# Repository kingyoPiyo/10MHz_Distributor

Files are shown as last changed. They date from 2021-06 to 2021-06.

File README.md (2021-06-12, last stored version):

# 10MHz_Distributor
GPSDOなどの10MHz基準信号の分配基板です。  
出力部に5段のBPFを搭載しており、入力信号をバッファリング＆正弦波へ波形整形してから出力します。 
 
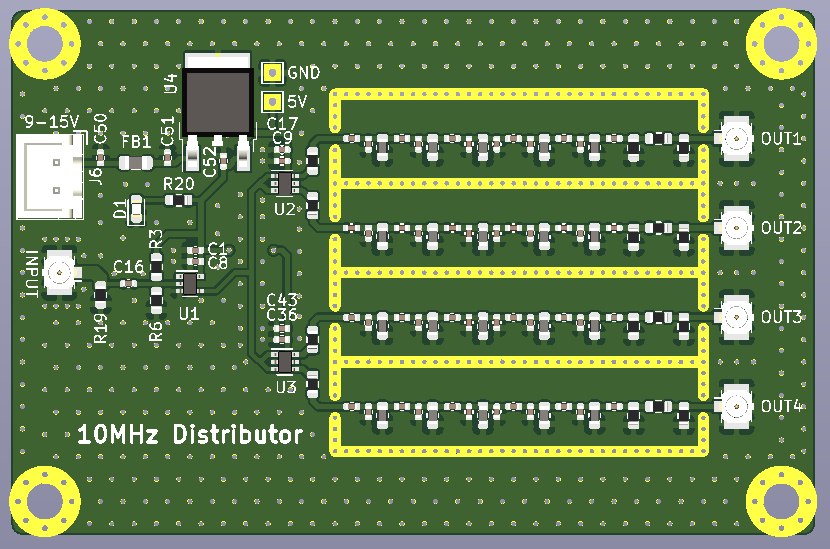
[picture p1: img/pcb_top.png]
  
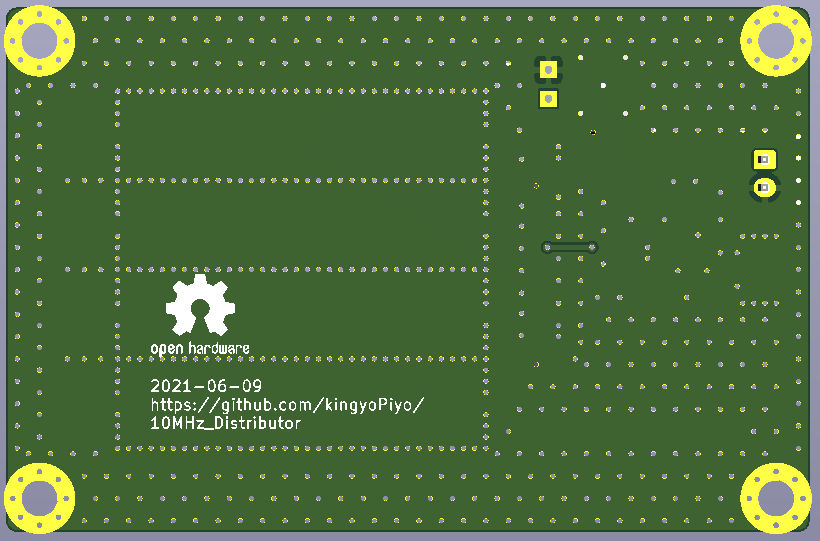
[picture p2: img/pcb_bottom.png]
  

# 諸特性
・・・部品到着、組み立て後に詳細測定予定・・・  

|  項目  |  仕様 |  備考  |
| --- | --- | --- |
|  電源電圧  |  9 ～ 15 V  | NJM7805耐圧は35V |
|  消費電流  |  約 xx mA  | 電源電圧12V, 4出力50Ω終端時 |
|  入力インピーダンス  |  約 xxx Ω  | R19にて50Ω終端可 |
|  入力信号レベル  |  xx ～ xx Vp-p  |  |
|  出力インピーダンス  |  50 Ω  |  |
|  出力信号レベル  |  xx ～ xx dBm  | 50Ω終端時 |
|  スプリアスレベル  |  < -xx dBm (2nd)<br>< -xx dBm (3rd)<br>< -xx dBm (4th)  | 50Ω終端時 |
|  SSB位相雑音  |  -xx dBc/Hz 10kHz offset<br>-xx dBc/Hz 30kHz offset<br>-xx dBc/Hz 100kHz offset  | 50Ω終端時<br>入力信号はxxx |

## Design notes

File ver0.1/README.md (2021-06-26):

# 10MHz_Distributor(ver 0.1)
GPSDOなどの10MHz基準信号の分配基板です。  
出力部に5段のBPFを搭載しており、入力信号をバッファリング＆正弦波へ波形整形してから出力します。 
 
  
  

# 諸特性
インダクタのQ値が考慮できておらず、通過帯域での減衰量が非常に大きくなりました。  
インダクタを変更して再設計します。（続く・・・）  
* インダクタ：LQW18ANR47J00  
* Q値：5.5@10MHz  
* DCR：5.3Ω@10MHz  

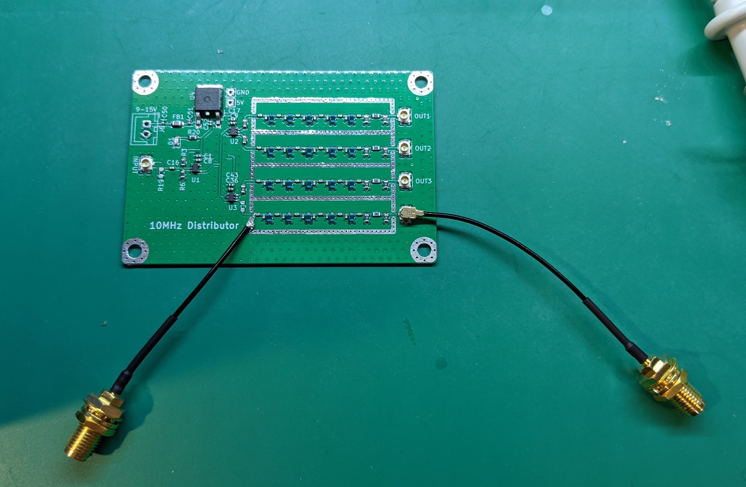
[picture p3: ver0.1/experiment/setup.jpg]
  
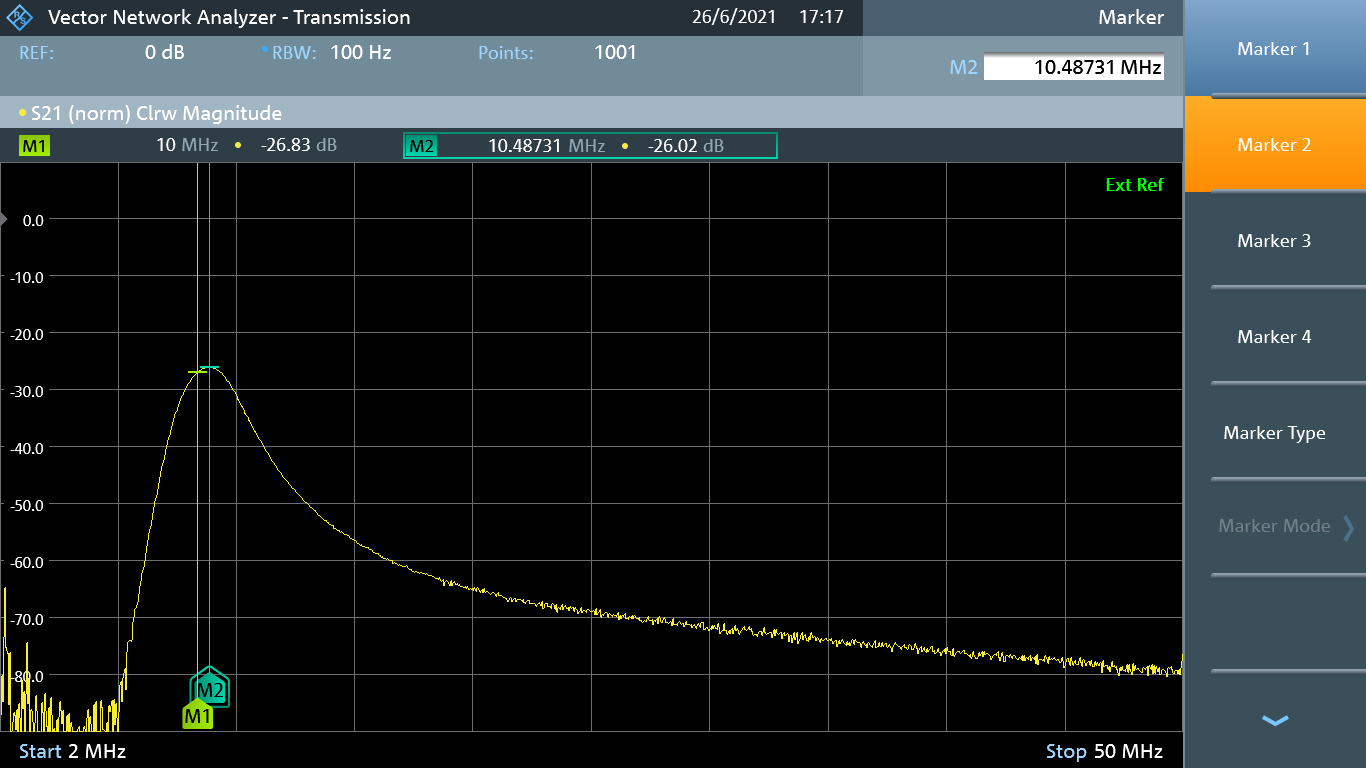
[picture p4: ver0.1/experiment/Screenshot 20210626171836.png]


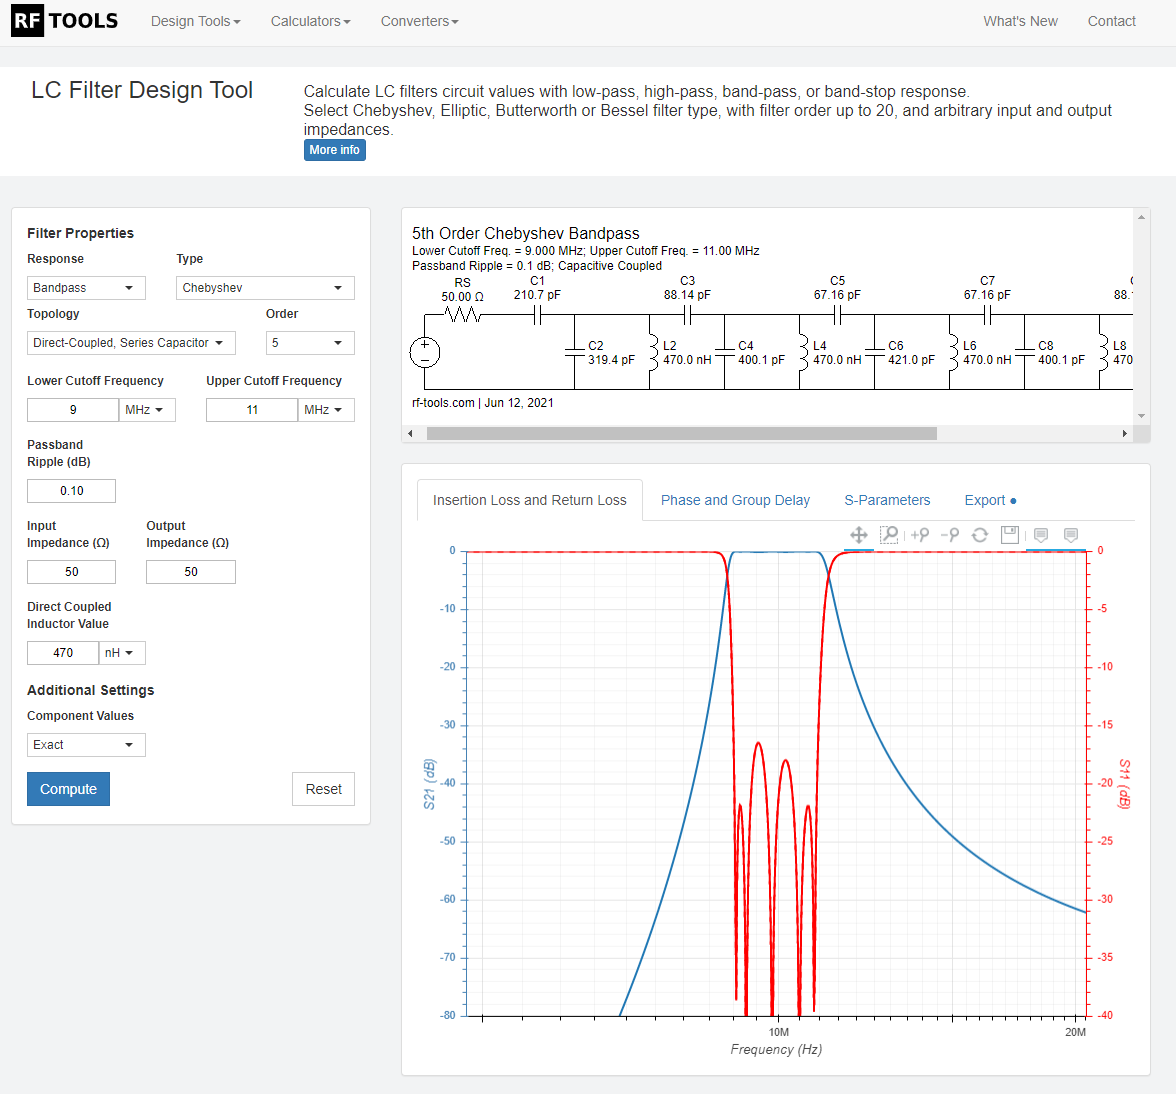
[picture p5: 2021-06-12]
ver0.1/LTspice/LCFilterDesignTool_cap.png

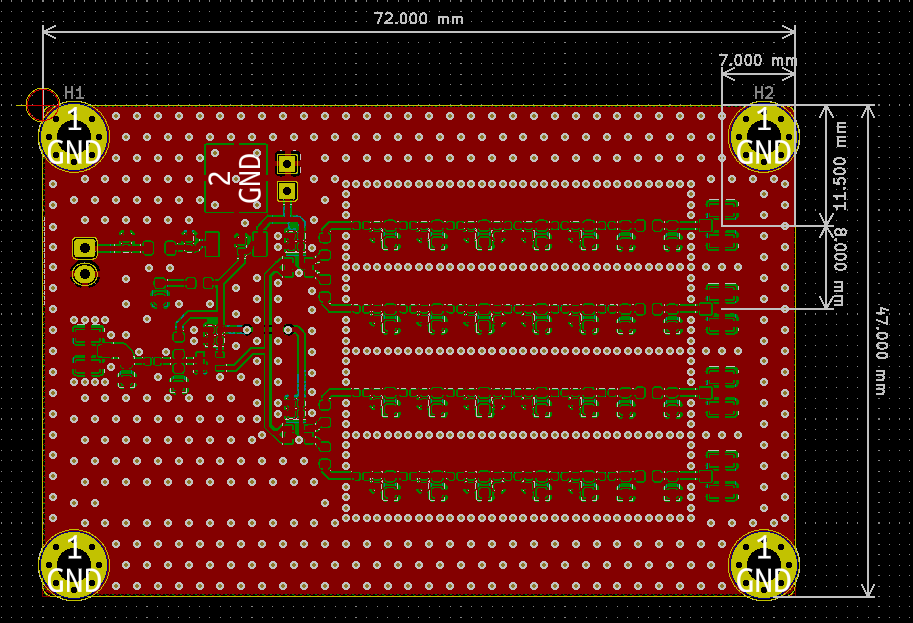
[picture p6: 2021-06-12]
ver0.1/img/pcb_size.png

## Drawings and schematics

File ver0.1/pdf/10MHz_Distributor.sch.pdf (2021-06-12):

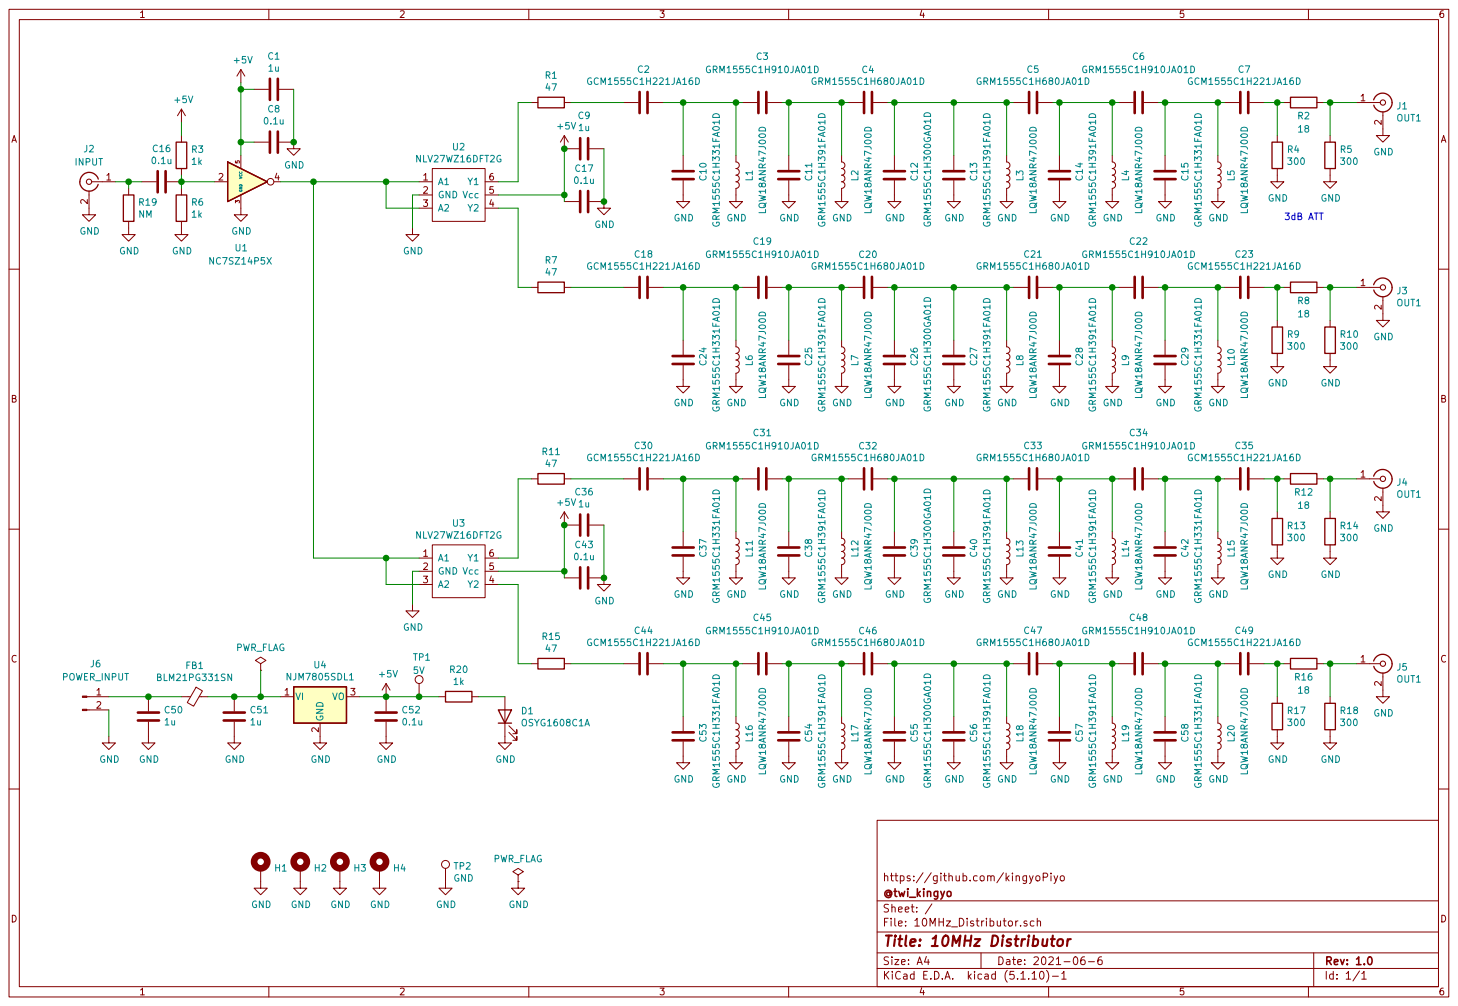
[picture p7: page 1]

https://github.com/kingyoPiyo C38 GRM1555C1H391FA01D

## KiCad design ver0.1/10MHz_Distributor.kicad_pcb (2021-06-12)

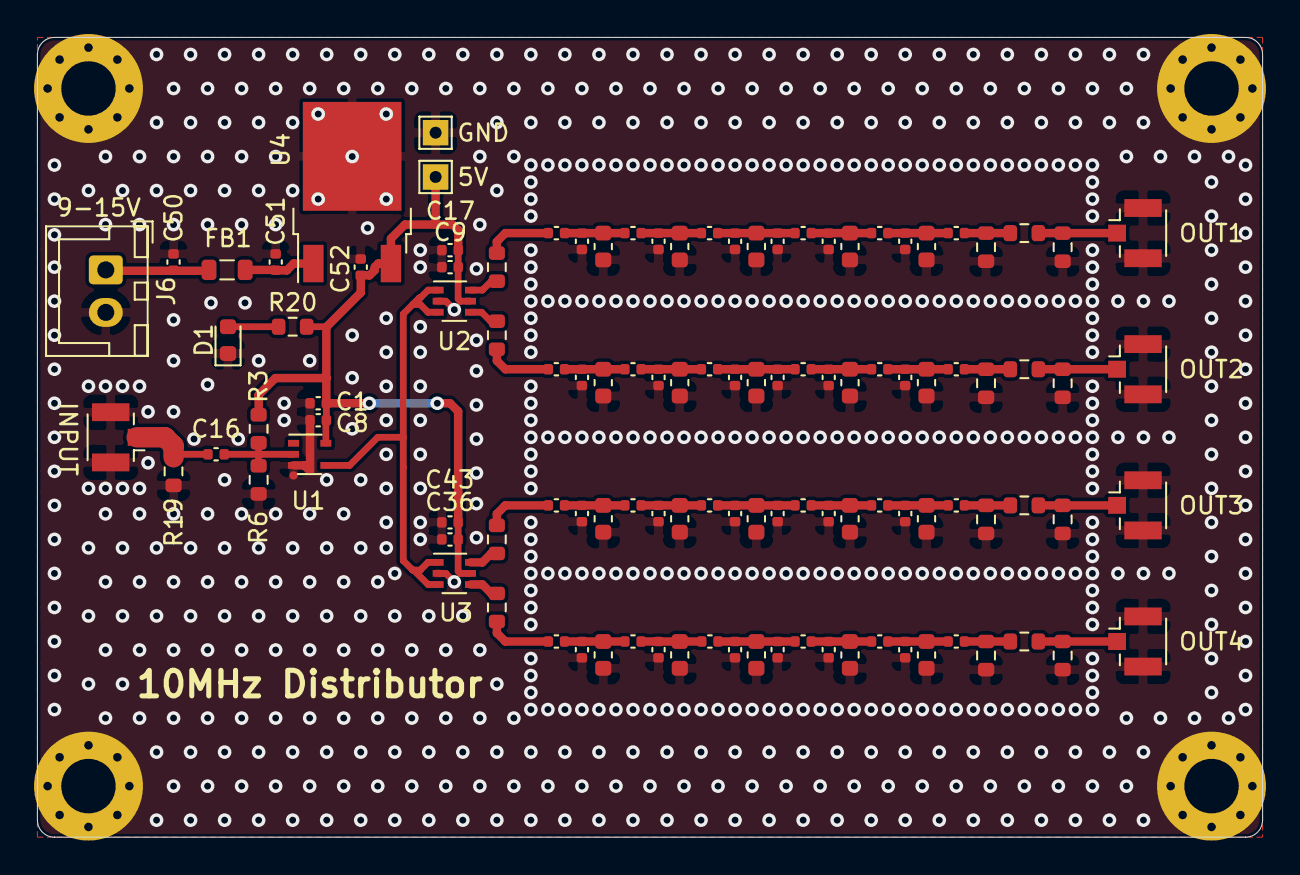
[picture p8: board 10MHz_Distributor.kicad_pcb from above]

Board: 2 copper layers, 72.0 x 47.0 mm, 116 parts (0 on the bottom side), 44 nets.

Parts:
C1, C9, C36, C50, C51: 1u; C_0402_1005Metric
C2, C7, C18, C23, C30, C35, C44, C49: GCM1555C1H221FA16D; C_0402_1005Metric
C3, C6, C19, C22, C31, C34, C45, C48: GRM1555C1H910JA01D; C_0402_1005Metric
C4, C5, C20, C21, C32, C33, C46, C47: GRM1555C1H680JA01D; C_0402_1005Metric
C8, C16, C17, C43, C52: 0.1u; C_0402_1005Metric
C10, C15, C24, C29, C37, C42, C53, C58: GRM1555C1H331FA01D; C_0402_1005Metric
C11, C13, C14, C25, C27, C28, C38, C40, C41, C54, C56, C57: GRM1555C1H391FA01D; C_0402_1005Metric
C12, C26, C39, C55: GRM1555C1H300GA01D; C_0402_1005Metric
D1: LED; LED_0603_1608Metric
FB1: BLM21PG331SN; L_0805_2012Metric
H1, H2, H3, H4: MountingHole_Pad; MountingHole_3.2mm_M3_Pad_Via
J1, J3, J4, J5: OUT1; U.FL_Hirose_U.FL-R-SMT-1_Vertical
J2: IN; U.FL_Hirose_U.FL-R-SMT-1_Vertical
J6: POWER_INPUT; JST_XH_B2B-XH-A_1x02_P2.50mm_Vertical
L1, L2, L3, L4, L5, L6, L7, L8, L9, L10, L11, L12, L13, L14, L15, L16, L17, L18, L19, L20: LQW18ANR47J00D; L_0603_1608Metric
R1, R7, R11, R15: 47R; R_0603_1608Metric
R2, R8, R12, R16: 17R6; R_0603_1608Metric
R3, R6, R20: 1k; R_0603_1608Metric
R4, R5, R9, R10, R13, R14, R17, R18: 292R4; R_0603_1608Metric
R19: NM; R_0603_1608Metric
TP1: 5V; TestPoint_THTPad_1.5x1.5mm_Drill0.7mm
TP2: GND; TestPoint_THTPad_1.5x1.5mm_Drill0.7mm
U1: TC7S14F / NC7SZ14P5XCT-ND; SOT-353_SC-70-5
U2, U3: NLV27WZ16DFT2G; SOT-363_SC-70-6
U4: NJM7805SDL1; TO-252-2

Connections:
+5V: C1.2, C8.2, C9.2, C17.2, C36.2, C43.2, C52.2, R3.1, R20.2, TP1.1, U1.5, U2.5, U3.5, U4.3
GND: C1.1, C8.1, C9.1, C10.2, C11.2, C12.2, C13.2, C14.2, C15.2, C17.1, C24.2, C25.2, C26.2, C27.2, C28.2, C29.2, C36.1, C37.2, C38.2, C39.2, C40.2, C41.2, C42.2, C43.1, C50.1, C51.1, C52.1, C53.2, C54.2, C55.2, C56.2, C57.2, C58.2, D1.1, H1.1, H2.1, H3.1, H4.1, J1.2, J2.2, J3.2, J4.2, J5.2, J6.2, L1.2, L2.2, L3.2, L4.2, L5.2, L6.2, L7.2, L8.2, L9.2, L10.2, L11.2, L12.2, L13.2, L14.2, L15.2, L16.2, L17.2, L18.2, L19.2, L20.2, R4.2, R5.2, R6.2, R9.2, R10.2, R13.2, R14.2, R17.2, R18.2, R19.2, TP2.1, U1.3, U2.2, U3.2, U4.2
unnamed: C2.2, R1.1
unnamed: C7.1, R2.2, R4.1
unnamed: C2.1, C3.2, C10.1, L1.1
unnamed: C3.1, C4.2, C11.1, L2.1
unnamed: C4.1, C5.2, C12.1, C13.1, L3.1
unnamed: C5.1, C6.2, C14.1, L4.1
unnamed: C6.1, C7.2, C15.1, L5.1
unnamed: C16.1, R3.2, R6.1, U1.2
unnamed: C16.2, J2.1, R19.1
unnamed: C18.1, C19.2, C24.1, L6.1
unnamed: C18.2, R7.1
unnamed: C19.1, C20.2, C25.1, L7.1
unnamed: C20.1, C21.2, C26.1, C27.1, L8.1
unnamed: C21.1, C22.2, C28.1, L9.1
unnamed: C22.1, C23.2, C29.1, L10.1
unnamed: C23.1, R8.2, R9.1
unnamed: C30.1, C31.2, C37.1, L11.1
unnamed: C30.2, R11.1
unnamed: C31.1, C32.2, C38.1, L12.1
unnamed: C32.1, C33.2, C39.1, C40.1, L13.1
unnamed: C33.1, C34.2, C41.1, L14.1
unnamed: C34.1, C35.2, C42.1, L15.1
unnamed: C35.1, R12.2, R13.1
unnamed: C44.1, C45.2, C53.1, L16.1
unnamed: C44.2, R15.1
unnamed: C45.1, C46.2, C54.1, L17.1
unnamed: C46.1, C47.2, C55.1, C56.1, L18.1
unnamed: C47.1, C48.2, C57.1, L19.1
unnamed: C48.1, C49.2, C58.1, L20.1
unnamed: C49.1, R16.2, R17.1
unnamed: C50.2, FB1.2, J6.1
unnamed: C51.2, FB1.1, U4.1
unnamed: D1.2, R20.1
unnamed: J1.1, R2.1, R5.1
unnamed: J3.1, R8.1, R10.1
unnamed: J4.1, R12.1, R14.1
unnamed: J5.1, R16.1, R18.1
unnamed: R1.2, U2.6
unnamed: R7.2, U2.4
unnamed: R11.2, U3.6
unnamed: R15.2, U3.4
unnamed: U1.4, U2.1, U2.3, U3.1, U3.3

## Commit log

2021-06-12 Add some files
    [10MHz_Distributor.kicad_pcb, 10MHz_Distributor.sch]
2021-06-26 Q値反映
2021-06-26 フォルダ移動
    [10MHz_Distributor.kicad_pcb, 10MHz_Distributor.sch]
2021-06-26 S21差し替え
